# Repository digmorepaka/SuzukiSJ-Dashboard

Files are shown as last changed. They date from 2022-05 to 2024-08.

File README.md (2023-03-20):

# SuzukiSJ-Dashboard
Insert module for a Suzuki SJ Jimny/Samurai '86-88.0 Instrument cluster with communications to speeduino ECU
ST7789 LCD

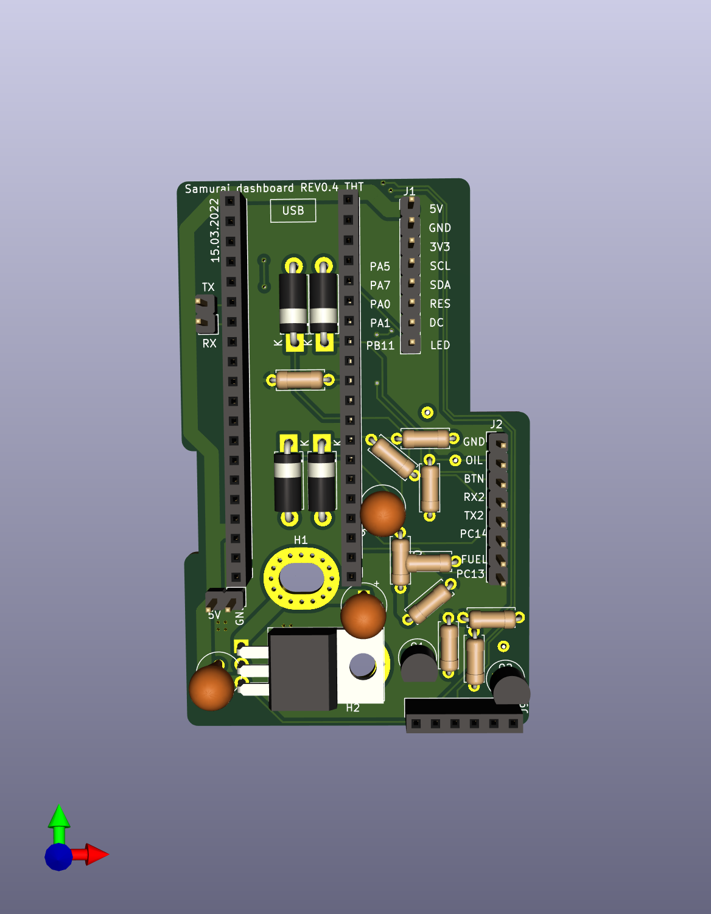
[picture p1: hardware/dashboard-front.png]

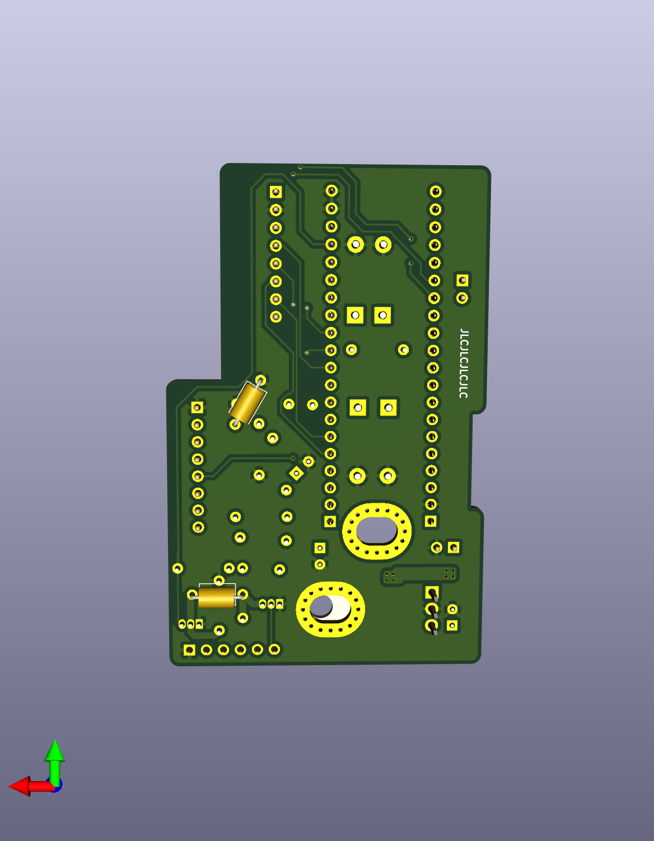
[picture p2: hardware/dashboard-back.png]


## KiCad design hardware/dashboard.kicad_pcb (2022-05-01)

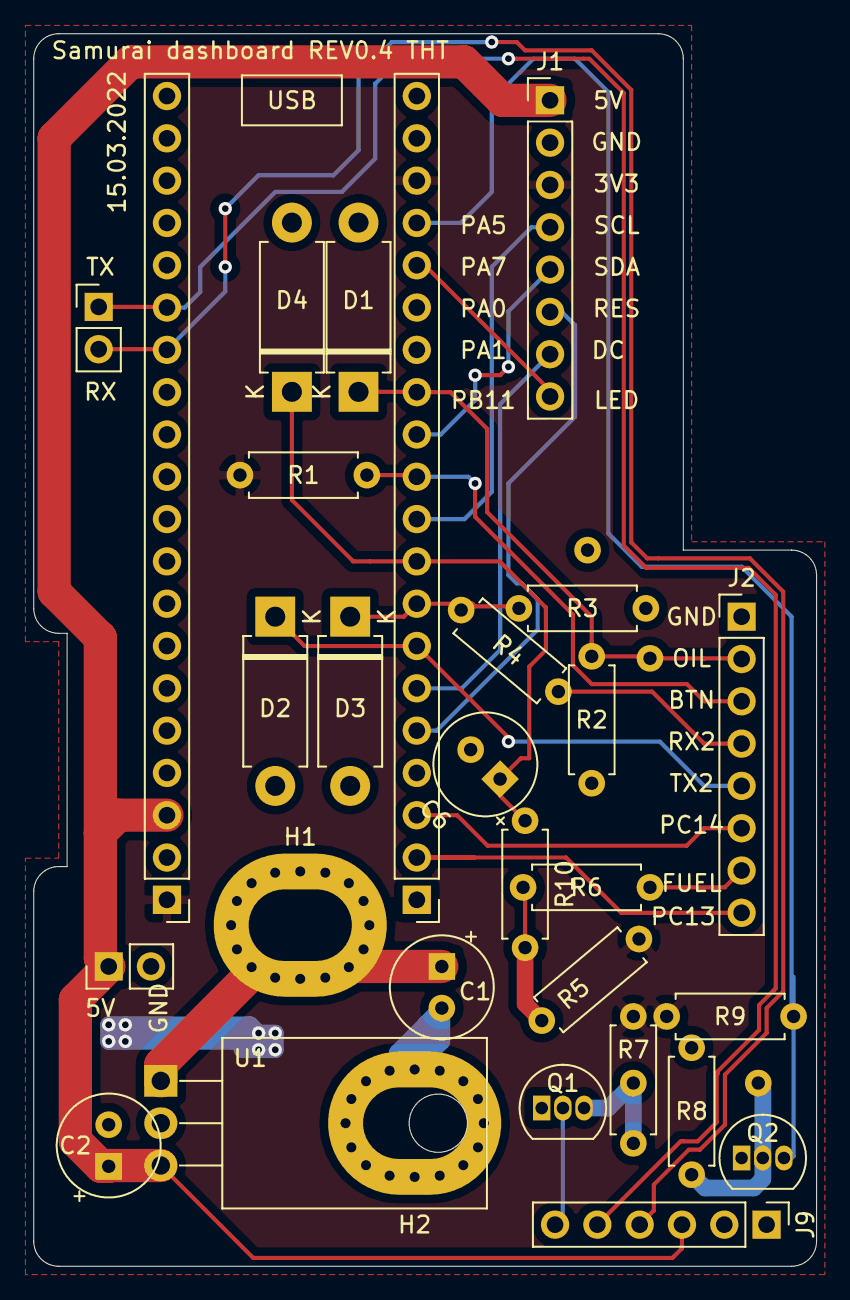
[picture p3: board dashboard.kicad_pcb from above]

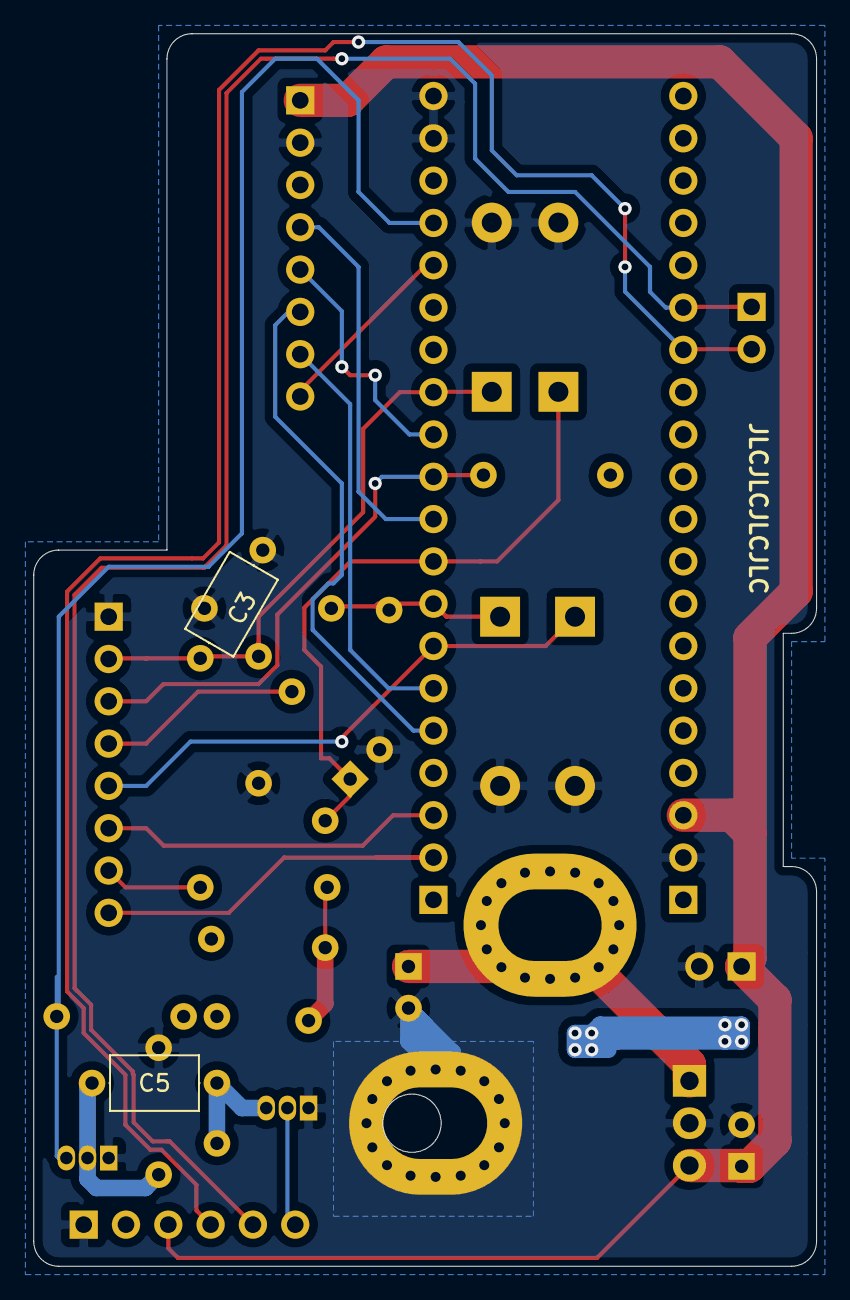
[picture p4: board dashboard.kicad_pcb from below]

Board: 2 copper layers, 47.0 x 74.0 mm, 31 parts (2 on the bottom side), 25 nets.

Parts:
C1: 10uF; CP_Radial_Tantal_D6.0mm_P2.50mm
C2: 47uF; CP_Radial_Tantal_D6.0mm_P2.50mm
C3: 1u; C_Axial_L5.1mm_D3.1mm_P7.50mm_Horizontal
C5: 1n; C_Axial_L5.1mm_D3.1mm_P7.50mm_Horizontal
C6: 10u; CP_Radial_Tantal_D6.0mm_P2.50mm
D1, D2, D3, D4: 3V6; D_DO-15_P10.16mm_Horizontal
H1: 12V; MountingHole_4.3x6.2mm_M4_Pad_Via
H2: GND; MountingHole_4.3x6.2mm_M4_Pad_Via
J1: LCD; PinHeader_1x08_P2.54mm_Vertical
J2: IO; PinHeader_1x08_P2.54mm_Vertical
J3: PWR; PinHeader_1x02_P2.54mm_Vertical
J4: prog; PinHeader_1x02_P2.54mm_Vertical
J7: STM32A; PinHeader_1x20_P2.54mm_Vertical
J8: STM32B; PinHeader_1x20_P2.54mm_Vertical
J9: FTDI; PinHeader_1x06_P2.54mm_Vertical
Q1, Q2: 2N3904; TO-92_Inline
R1, R9: 10K; R_Axial_DIN0207_L6.3mm_D2.5mm_P7.62mm_Horizontal
R2: 150; R_Axial_DIN0207_L6.3mm_D2.5mm_P7.62mm_Horizontal
R3: 330; R_Axial_DIN0207_L6.3mm_D2.5mm_P7.62mm_Horizontal
R4: 230; R_Axial_DIN0207_L6.3mm_D2.5mm_P7.62mm_Horizontal
R5, R6: 120; R_Axial_DIN0207_L6.3mm_D2.5mm_P7.62mm_Horizontal
R7: 100R; R_Axial_DIN0207_L6.3mm_D2.5mm_P7.62mm_Horizontal
R8, R10: 100K; R_Axial_DIN0207_L6.3mm_D2.5mm_P7.62mm_Horizontal
U1: L7805; TO-220-3_Horizontal_TabDown

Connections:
+3V3: J1.3, J7.18, J8.1, R1.2, R5.2, R7.1, R9.1
+5V: C2.1, J1.1, J3.1, J8.3, J9.3, U1.3
+12V: C1.1, H1.1, U1.1
DTR: J9.6, Q1.2
Fuel_level: J2.7, R6.1
GND: C1.2, C2.2, C3.2, C6.2, D1.2, D2.2, D3.2, D4.2, H2.1, J1.2, J2.1, J3.2, J7.19, J7.20, J8.2, J9.1, Q1.1, Q2.1, R2.1, R3.1, R8.2, U1.2
unnamed: C5.1, Q2.2, R8.1
unnamed: C5.2, Q1.3, R7.2
unnamed: R5.1, R6.2, R10.2
PA0: J1.6, J7.5
PA1: J1.7, J7.6
PA2: D2.1, J2.5, J7.7
PA3: D3.1, J7.8, R3.2, R4.2
PA4: C6.1, D4.1, J7.9, R10.1
PA5: J1.4, J7.10
PA6: J2.3, J7.11, R1.1
PA7: J1.5, J7.12
PA9: J4.1, J8.15, J9.5
PA10: J4.2, J8.14, J9.4
PB0: C3.1, D1.1, J2.2, J7.13, R2.2
PB11: J1.8, J7.16
PC13: J2.8, J7.2
PC14: J2.6, J7.3
RESET: J7.17, Q2.3, R9.2
RX2: J2.4, R4.1

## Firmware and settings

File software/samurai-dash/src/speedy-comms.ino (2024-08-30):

#include <TFT_eSPI.h>
#include <SPI.h>
#include <Adafruit_NeoPixel.h>
#include "speedy-comm.h"
#include "Screen.h"
#include "MainScreen.h"
#include "TuneScreen.h"

Adafruit_NeoPixel pixels = Adafruit_NeoPixel(3, PB11, NEO_GRB + NEO_KHZ800);

TFT_eSPI tft = TFT_eSPI();
HardwareSerial Serial2(USART2); // for some reason this isn't defined in arduino_core_stm32

bool dataUpdated = false;
int z = 0;
int oilraw = 0;
int pageNumber = 0;
int oldPage = 0;
int fuelraw = 0;
int fuelError = 0;
int oilError = 0;
volatile bool nextScreen = false;
Screen* currentScreen = NULL;
struct ImportantData importantData = {0};

void changeScreen(Screen* screen) {
    tft.fillScreen(TFT_BLACK);

    if (currentScreen != NULL) {
        currentScreen->OnExit();
    }
    delete currentScreen;
    currentScreen = screen;
    currentScreen->OnEnter();
}

void addUI()
{
    static unsigned long last_interrupt_time = 0;
    unsigned long interrupt_time = millis();
    if (interrupt_time - last_interrupt_time > 200)
    {
        nextScreen = true;   
    }
    last_interrupt_time = interrupt_time;
}

void  setup() {
    Serial.begin(115200); // for debugging

    // Speeduino init
    Serial2.begin(115200); // baudrate for Speeduino is 115200

    pinMode(PB0, INPUT_ANALOG);
    pinMode(PA4, INPUT_ANALOG);
    pinMode(PA6, INPUT_PULLUP);
    attachInterrupt(digitalPinToInterrupt(PA6), addUI, FALLING);
    analogReadResolution(12);
    // Display init
    tft.init(); // initialize a ST7789 chip, 240×240 pixels
    tft.setRotation(2);
    tft.fillScreen(TFT_BLACK);
 
    delay(2000);
    changeScreen(new MainScreen());
    //changeScreen(new TuneScreen());
    pixels.begin();
    pixels.setBrightness(100);
}

void updateSensorsData()
{
    fuelraw = analogRead(PA4);
    oilraw = analogRead(PB0);
    // importantData.OILPRSR = map(oilraw,  696, 3675, 0, 100);
    importantData.OILPRSR = (((float)oilraw - 670.0f) / (3675.0f - 670.0f)) * 10.0f; // min max  min
    // Serial2.printf("Data %.2f\n", importantData.OILPRSR);
}

bool processSpeeduinoNMessage()
{
    static uint8_t buffer[256];
    if (Serial2.read() != 'n') {
        // FAILED!!!
        return false;
    }
    Serial2.read();
    //Serial.println("Got data");
    byte length = Serial2.read();
    //byte length = 75;
    int returnedLength = Serial2.readBytes(buffer, length);
    //Serial.printf("Length: %d, returned: %d\n",  length, returnedLength);

    if (
        (((uint16_t)buffer[15] << 8) | buffer[14]) > 8000 || // RPM
        (buffer[6] - 40) > 142 ||  //clt
        (buffer[7] - 40) > 142 ||  //iat
        (buffer[10] < 80) || buffer[10] > 200
    )
    {
        return true;
    } 

    importantData.RPM = ((uint16_t)buffer[15] << 8) | buffer[14];
    importantData.MAP = ((uint16_t)buffer[5] << 8) | buffer[4];
    importantData.Voltage = buffer[9];
    importantData.AFR = buffer[10];
    importantData.TPS = buffer[24];
    importantData.IAT = buffer[6] - 40;
    importantData.CLT = buffer[7] - 40;

    
    updateSensorsData();

    dataUpdated = true;
    return true;
}

void updateLeds() {
    if (dataUpdated) {
        switch (importantData.fuelLevel)
        {
            case 0:
                pixels.setPixelColor(1, pixels.Color(255, 0, 0));
                break;
            case 1:
                pixels.setPixelColor(1, pixels.Color(255, 0, 0));
                break;
            case 2:
                pixels.setPixelColor(1, pixels.Color(255, 70, 10));
                break;
            case 3:
                pixels.setPixelColor(1, pixels.Color(0, 255, 0));
                break;
            case 4:
                pixels.setPixelColor(1, pixels.Color(0, 255, 0));
                break;
            case 5:
                pixels.setPixelColor(1, pixels.Color(0, 255, 0));
                break;
        }

        if (importantData.CLT < 55)
        {
            pixels.setPixelColor(0,  pixels.Color(0, 0, 255));
        }
        else if (importantData.CLT > 55 && importantData.CLT < 95)
        {
            pixels.setPixelColor(0, pixels.Color(0, 255, 0));
        }
        else if (importantData.CLT > 95)
        {
            pixels.setPixelColor(0, pixels.Color(255, 0, 0));
        }

        pixels.show();
    }
    //min 2085, max 2730 calculated
    if (fuelraw > 2000 && fuelraw < 2281)
    { // second value should be minimum for engine to run
        importantData.fuelLevel = 5;
    }
    /*else if (fuelraw > 2101 && fuelraw < 2210)
    {
        importantData.fuelLevel = 4;
    }*/
    else if (fuelraw > 2280 && fuelraw < 2480)
    {
        importantData.fuelLevel = 3;
    }
    else if (fuelraw > 2481 && fuelraw < 2610)
    {
        importantData.fuelLevel = 2;
    }
    else if (fuelraw > 2611 && fuelraw < 2680)
    {
        importantData.fuelLevel = 1;
    }
    else if (fuelraw < 2680)
    {
        importantData.fuelLevel = 0;
    }
    //Serial.println(fuelraw);
    
    if (oilraw < 650 || oilraw > 3750)
    {
        oilError = 1;
    }
    else
    {
        oilError = 0;
    }
    
    if (fuelraw < 1980 || fuelraw > 3000)
    {
        fuelError = 1;
        importantData.fuelLevel = 0;
    }
    else
    {
        fuelError = 0;
    }
    if (oilError || fuelError)
    {
        pixels.setPixelColor(2, pixels.Color(255, 0, 0));
    }
    else
    {
        pixels.setPixelColor(2, pixels.Color(0, 0, 0));
    }
}

void loop()
{
    
    static uint8_t speeduinoState = 1;
    { // Speeduino handling
        if (speeduinoState == 1)
        {
            //Serial.println("Sending n");
            Serial2.write('n');
            speeduinoState = 2;
        }
        else if (speeduinoState == 2 && Serial2.available() >= 75)
        {
            if  (processSpeeduinoNMessage()) {
                speeduinoState = 0;
            }
        }
    }
    { // Data Updating
        static uint32_t lastUpdateTime = 0;
        if (millis() - lastUpdateTime >= 150) {
            speeduinoState = 1;
            lastUpdateTime =  millis();
        }
    }

    if (nextScreen) {
        pageNumber = (pageNumber + 1) % 2;
        switch (pageNumber)
        {
        case 0:
            changeScreen(new MainScreen());
            break;
        case 1:
            changeScreen(new TuneScreen());
            break;
        }
        nextScreen = false;
    }

    //zobrauje, necita ?

    static uint32_t lastDataUpdateTime = millis();

    if (dataUpdated) {
        lastDataUpdateTime = millis();
    } else {
        if (millis() - lastDataUpdateTime >= 5000) {
            lastDataUpdateTime = millis();
            updateSensorsData();
            dataUpdated = true;
        }
    }

    updateLeds();
    currentScreen->Tick();
    currentScreen->Render();

    if (dataUpdated) {
        dataUpdated = false;
    }
}

void fillRectInside(int32_t x, int32_t y, int32_t w, int32_t h, uint32_t color)
{
    tft.fillRect(x + 1, y + 1, w - 2, h - 2, color);
}


/*
Red: 0xF800
Green: 0x07E0
Blue: 0x001F
Orange: 0xFDA0

Dark red: 0x4004
Dark green: 0x03E0
Dark blue: 
Dark orange: 0xA100

Main Page


Frame
  // Rectangle Fuel
    tft.drawRect(18,  18, 142, 160, TFT_WHITE);
    //  Rectangle   Temperature
    tft.drawRect(178, 18, 44, 160, TFT_WHITE);

    // Lines Fuel
    tft.drawFastHLine(18, 44, 142, TFT_WHITE);
    tft.drawFastHLine(18, 112, 142, TFT_WHITE);
    tft.drawFastHLine(18, 152, 142, TFT_WHITE);

    // Lines  Tempreature
    tft.drawFastHLine(178, 44, 44, TFT_WHITE);
    tft.drawFastHLine(178, 152, 44, TFT_WHITE);

Text

    tft.setCursor(18, 178 + 5);
    tft.setTextColor(TFT_WHITE, TFT_BLACK);
    tft.setTextSize(3);
    tft.print("RPM:");
    // tft.setTextColor(TFT_GREEN, TFT_BLACK);
    tft.setCursor(18, 178 + 5 + 20 +5);
    tft.print("OIL:");

5/5 fuel
    // Rectangles Fuel
    tft.fillRect(18, 18, 142, 26, TFT_GREEN);
    tft.fillRect(18, 44, 142, 86, TFT_GREEN);
    tft.fillRect(18, 112, 142, 40, TFT_GREEN);
    tft.fillRect(18, 152, 142, 26, TFT_GREEN);
4/5 fuel 
    // Rectangles Fuel
    tft.fillRect(18, 18, 142, 26, TFT_GREEN);
    tft.fillRect(18, 44, 142, 86, TFT_GREEN);
    tft.fillRect(18, 112, 142, 40, TFT_ORANGE);
    tft.fillRect(18, 152, 142, 26, TFT_RED);

3/5  fuel
    // Rectangles Fuel
    tft.fillRect(18, 18, 142, 26, TFT_DARKGREEN);
    tft.fillRect(18, 44, 142, 86, TFT_GREEN);
    tft.fillRect(18, 112, 142, 40, TFT_ORANGE);
    tft.fillRect(18, 152, 142, 26, TFT_RED);
2/5 fuel
    // Rectangles Fuel
    tft.fillRect(18, 18, 142, 26, TFT_DARKGREEN);
    tft.fillRect(18, 44, 142, 86, TFT_DARKGREEN);
    tft.fillRect(18, 112, 142, 40, TFT_ORANGE);
    tft.fillRect(18, 152, 142, 26, TFT_RED);
1/5 fuel
    // Rectangles Fuel
    tft.fillRect(18, 18, 142, 26, TFT_DARKGREEN);
    tft.fillRect(18, 44, 142, 86, TFT_DARKGREEN);
    tft.fillRect(18, 112, 142, 40, 0xA100);
    tft.fillRect(18, 152, 142, 26, TFT_RED);
0/5 fuel
    // Rectangles Fuel
    tft.fillRect(18, 18, 142, 26, TFT_DARKGREEN);
    tft.fillRect(18, 44, 142, 86, TFT_DARKGREEN);
    tft.fillRect(18, 112, 142, 40, 0xA100);
    tft.fillRect(18, 152, 142, 26, 0x4004);

3/3 CLT
    // Rectangles Temperature
    tft.fillRect(178, 18, 44, 26, TFT_RED);
    tft.fillRect(178, 44, 44, 126, TFT_RED);
    tft.fillRect(178, 152, 44, 26, TFT_RED);

2/3  CLT
    // Rectangles Temperature
    tft.fillRect(178, 18, 44, 26, 0x4004);
    tft.fillRect(178, 44, 44, 126, TFT_GREEN);
    tft.fillRect(178, 152, 44, 26, TFT_BLUE);

1/3  CLT
     // Rectangles Temperature
    tft.fillRect(178, 18, 44, 26, 0x4004);
    tft.fillRect(178, 44, 44, 126, TFT_DARKGREEN);
    tft.fillRect(178, 152, 44, 26, TFT_BLUE);

    
    
    
    
    
    
    
*/

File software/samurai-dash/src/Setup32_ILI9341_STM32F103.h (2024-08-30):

//////////////////////////////////////////////////////////////
// Setup for STM32F103 (e.g. Blue Pill) and ILI9341 display //
//////////////////////////////////////////////////////////////

// Last update by Bodmer: 14/1/20

// Define STM32 to invoke STM32 optimised driver
#define STM32

// Define the TFT display driver
#define ST7789_DRIVER
//#define ILI9481_DRIVER

// MOSI and SCK do not need to be defined, connect:
//  - Arduino SCK (Blue Pill pin A5)  to TFT SCK
//  - Arduino MOSI (Blue Pill pin A7) to TFT SDI (may be marked SDA or MOSI)
//  - Optional to read TFT: Arduino MISO (Blue Pill pin A6) to TFT SDO (may be marked MISO or may not exist on TFT)
//  Note: not all TFT's support reads

// reminder: Blue Pill SPI pins are SCK=A5, MISO = A6, MOSI=A7

// Can use Ardiuno pin references, arbitrary allocation, TFT_eSPI controls chip select
#define TFT_CS -1   // Chip select control pin to TFT CS
#define TFT_DC PA1  // Data Command control pin to TFT DC (may be labelled RS = Register Select)
#define TFT_RST PA0 // Reset pin to TFT RST (or RESET)

//#define TFT_RST  -1   // Set TFT_RST to -1 if the display RESET is connected to processor reset
// Use an Arduino pin for initial testing as connecting to processor reset
// may not work (due to variations in display design)

//#define TOUCH_CS A4 // Connect to T_CS (Touch controller chip select) if XPT2046 is connected to SPI bus
// You may need to wire the touch controller to the processor in addition to the TFT
// For example on some boards the pins are labelled:
// T_IRQ - no connection to processor
// T_DO  - connect to processor MISO
// T_DIN - connect to processor MOSI
// T_CS  - connect to processor pin specified by TOUCH_CS above
// T_SCK - connect to processor SCK

#define LOAD_GLCD  // Font 1. Original Adafruit 8 pixel font needs ~1820 bytes in FLASH
#define LOAD_FONT2 // Font 2. Small 16 pixel high font, needs ~3534 bytes in FLASH, 96 characters
#define LOAD_FONT4 // Font 4. Medium 26 pixel high font, needs ~5848 bytes in FLASH, 96 characters
#define LOAD_FONT6 // Font 6. Large 48 pixel font, needs ~2666 bytes in FLASH, only characters 1234567890:-.apm
#define LOAD_FONT7 // Font 7. 7 segment 48 pixel font, needs ~2438 bytes in FLASH, only characters 1234567890:-.
#define LOAD_FONT8 // Font 8. Large 75 pixel font needs ~3256 bytes in FLASH, only characters 1234567890:-.
#define LOAD_GFXFF // FreeFonts. Include access to the 48 Adafruit_GFX free fonts FF1 to FF48 and custom fonts

// STM32 support for smooth fonts via program memory (FLASH) arrays
#define SMOOTH_FONT

// Assuming the processor clock is 72MHz:
#define SPI_FREQUENCY 36000000 // 36MHz SPI clock
//#define SPI_FREQUENCY  18000000   // 18MHz SPI clock

#define SPI_READ_FREQUENCY 12000000 // Reads need a slower SPI clock

//#define SPI_TOUCH_FREQUENCY  2500000 // Must be very slow

// This has no effect, transactions are automatically enabled for STM32
//#define SUPPORT_TRANSACTIONS
#define TFT_HEIGHT 240
#define TFT_WIDTH 240
#define TFT_RGB_ORDER TFT_BGR
